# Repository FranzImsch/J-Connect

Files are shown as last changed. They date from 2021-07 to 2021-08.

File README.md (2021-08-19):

# J-Link Adapter Boards

20P JTAG to TAG-Connect TC2030 and  
20P JTAG to 10P JTAG (1.27mm) adapter boards.

### Features:
* 5V to 3.3V LDO and power good LED,
* button to reset the target device,
* VCOM breakout.

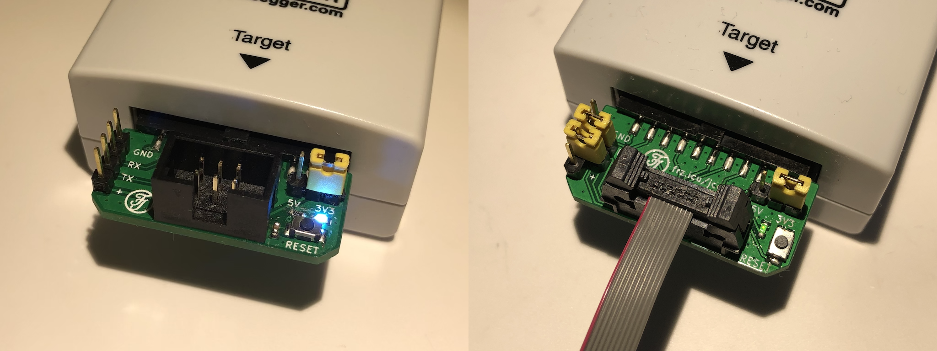
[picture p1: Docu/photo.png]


### PCB
The ideal PCB thickness would be 2.0mm, but 1.6mm is much cheaper and works as well.

## Tag-Connect Adapter
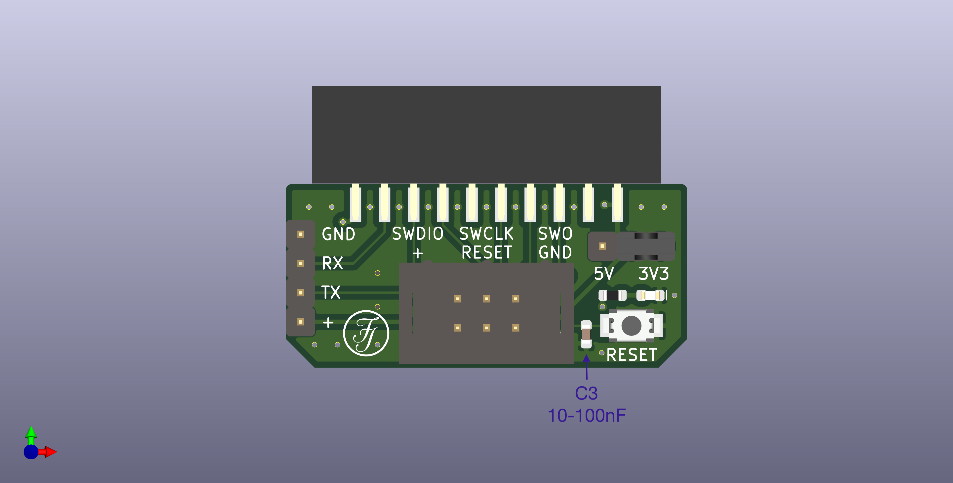
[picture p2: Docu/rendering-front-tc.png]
Front-Rendering

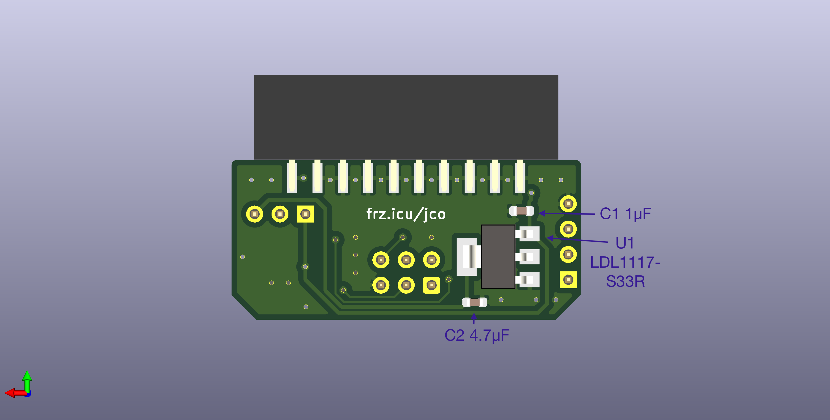
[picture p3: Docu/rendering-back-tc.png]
Back-Rendering


## 10P Adapter
A jumper can be added to connect RX and TX to the pins 7 and 8 respectively. (TX and RX are not in the standard 10P pinout!)  

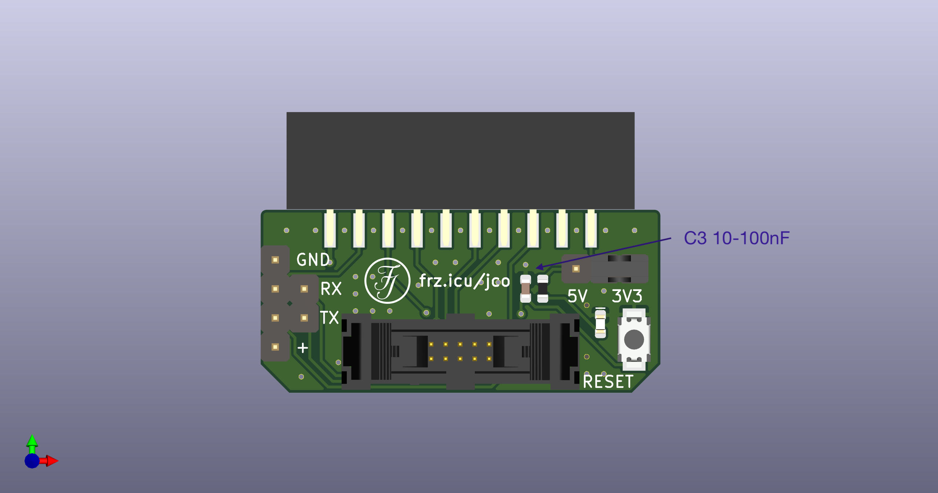
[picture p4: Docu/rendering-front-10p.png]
Front-Rendering

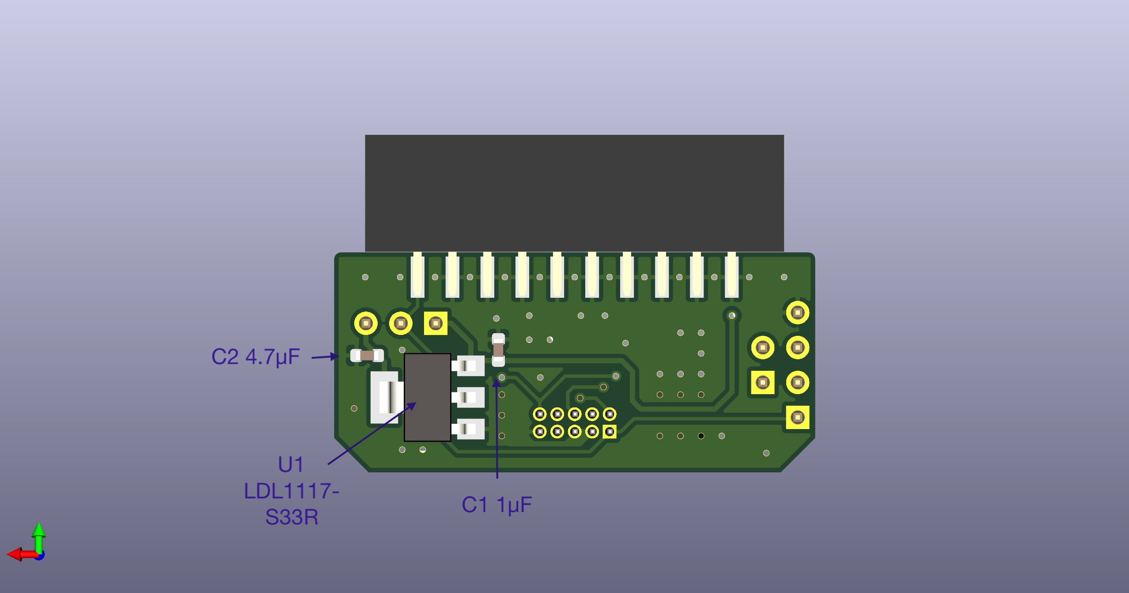
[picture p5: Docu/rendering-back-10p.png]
Back-Rendering


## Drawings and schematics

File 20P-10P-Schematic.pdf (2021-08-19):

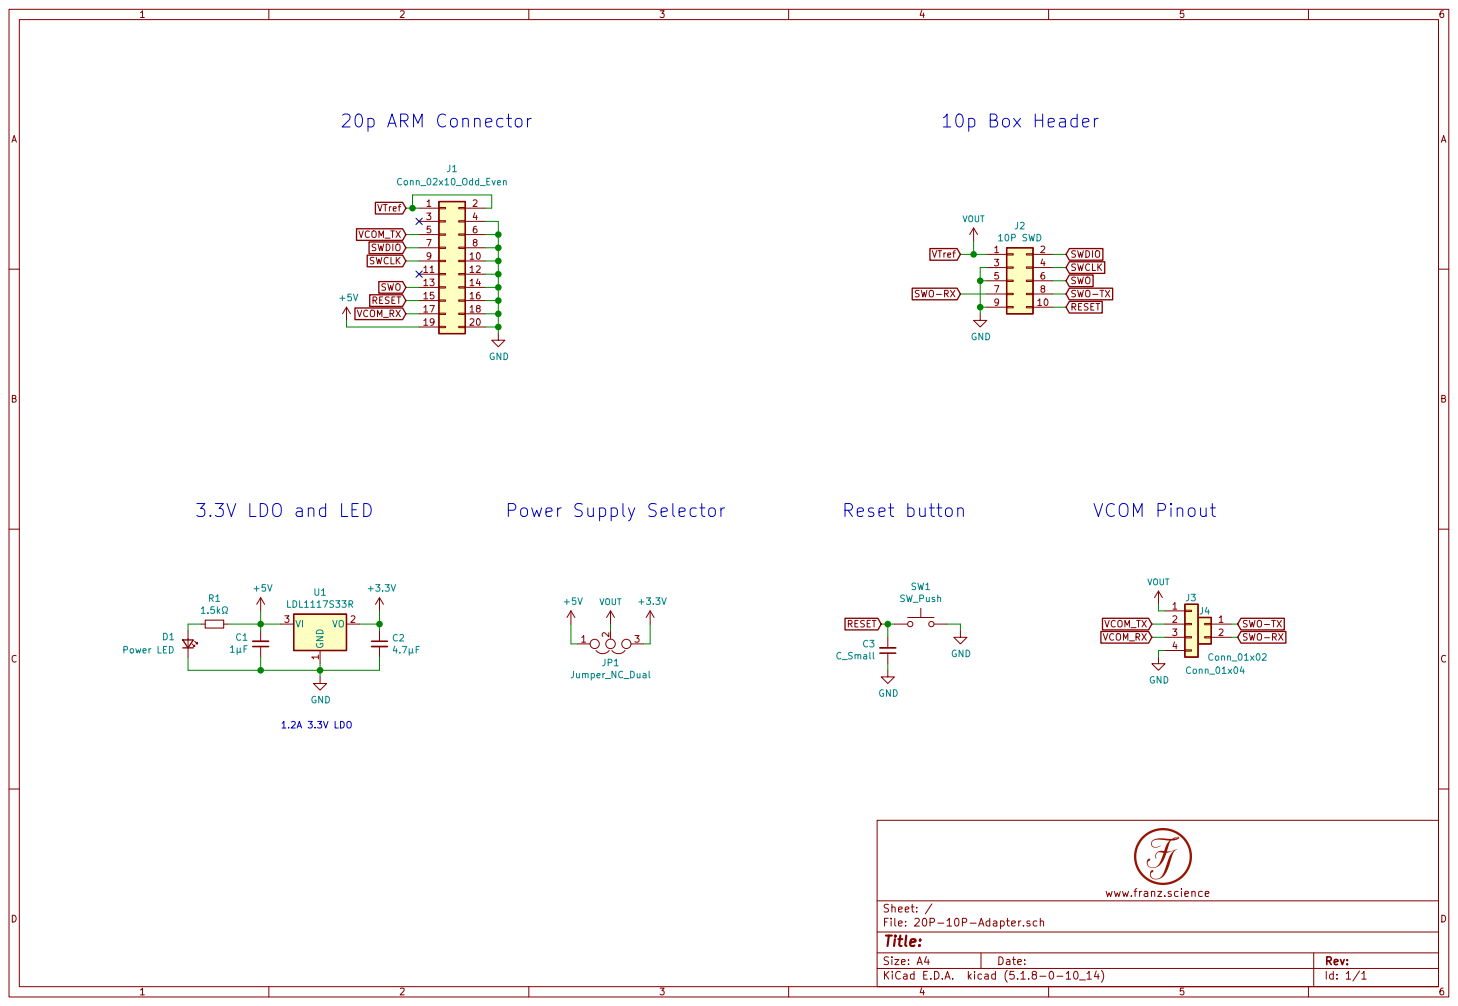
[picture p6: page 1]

File: 20P-10P-Adapter.sch Sheet: /
Id: 1/1 Title:

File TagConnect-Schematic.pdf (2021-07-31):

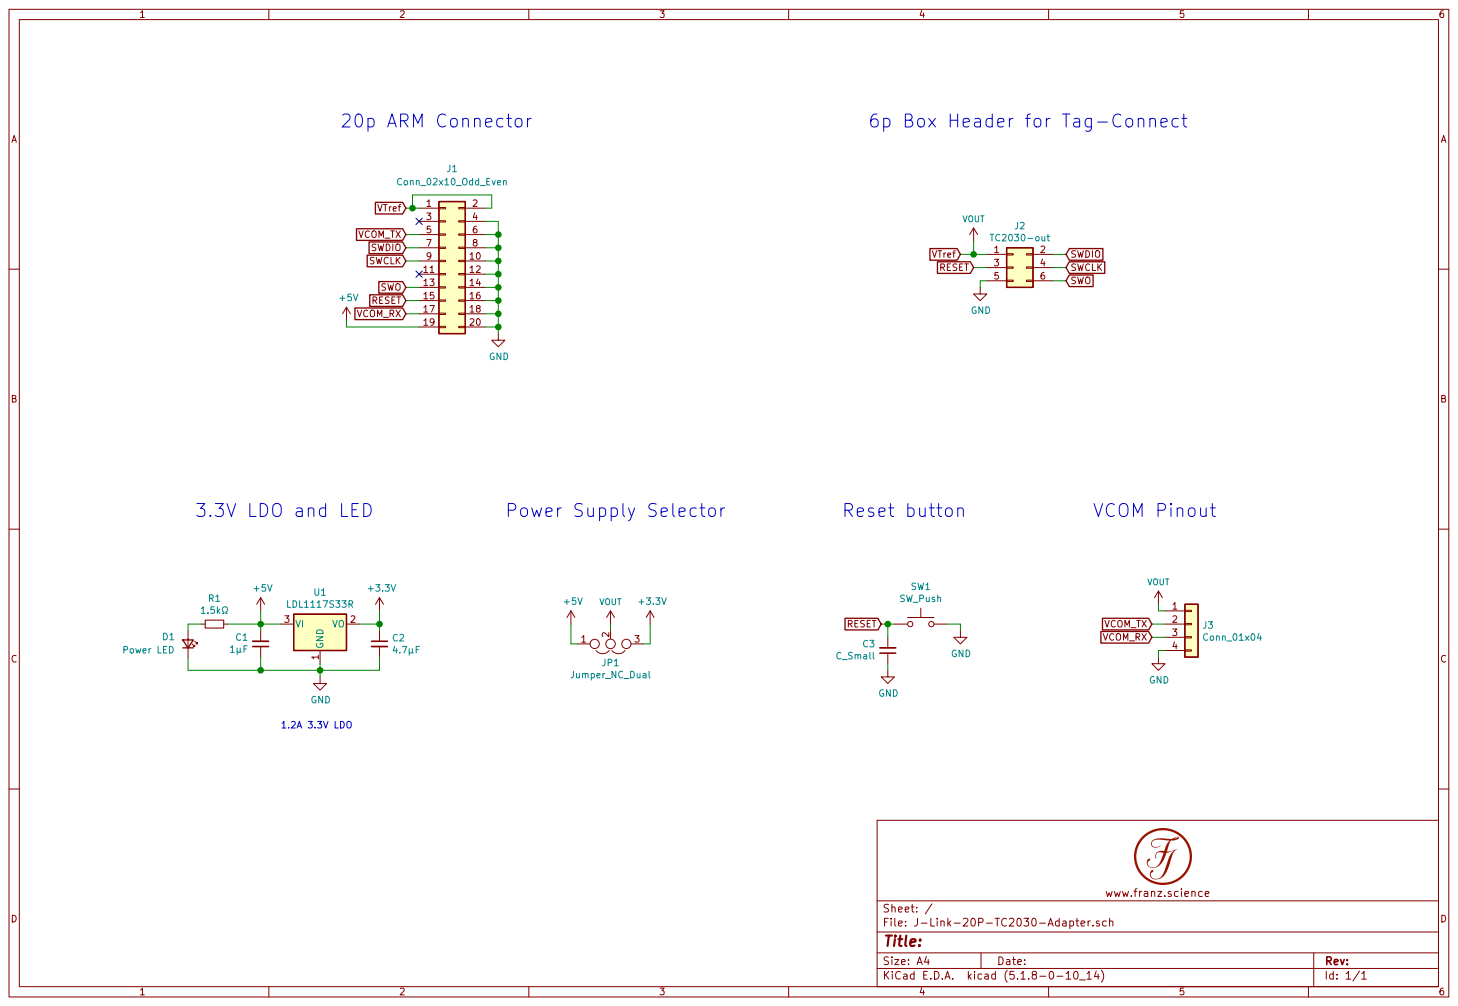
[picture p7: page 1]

File: J-Link-20P-TC2030-Adapter.sch Sheet: /
Id: 1/1 Title:

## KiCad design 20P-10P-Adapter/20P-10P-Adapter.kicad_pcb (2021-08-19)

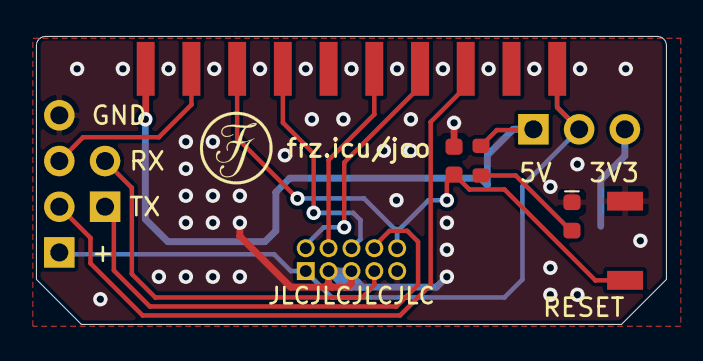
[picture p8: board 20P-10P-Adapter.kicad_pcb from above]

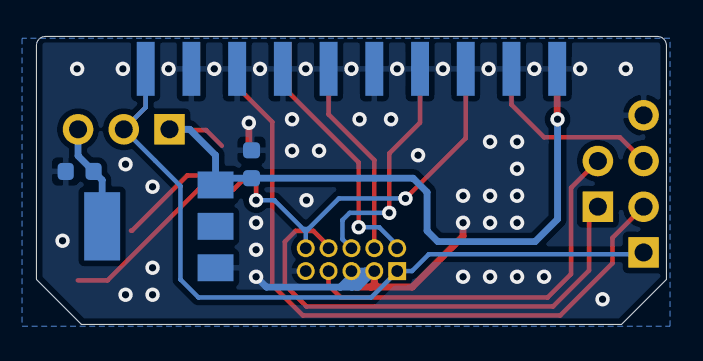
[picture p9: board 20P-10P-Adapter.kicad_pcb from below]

Board: 2 copper layers, 35.0 x 16.0 mm, 12 parts (3 on the bottom side), 13 nets.

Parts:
C1: 1µF; C_0603_1608Metric
C2: 4.7µF; C_0603_1608Metric
C3: C_Small; C_0603_1608Metric
D1: Power LED; LED_0603_1608Metric
J1: Conn_02x10_Odd_Even; Jlink-Conn-20P-PCB
J2: 10P SWD; IDC-Header_2x05_P1.27mm_Latch_Vertical
J3: Conn_01x04; PinHeader_1x04_P2.54mm_Vertical
J4: Conn_01x02; PinHeader_1x02_P2.54mm_Vertical
JP1: Jumper_NC_Dual; PinHeader_1x03_P2.54mm_Vertical
R1: 1.5kΩ; R_0603_1608Metric
SW1: SW_Push; SW_DIP_SPSTx01_Push_TSA343G00-250J2
U1: LDL1117S33R; SOT-223-3_TabPin2

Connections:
+3V3: C2.1, JP1.3, U1.2
+5V: C1.2, J1.19, JP1.1, R1.1, U1.3
GND: C1.1, C2.2, C3.1, D1.1, J1.4, J1.6, J1.8, J1.10, J1.12, J1.14, J1.16, J1.18, J1.20, J2.3, J2.5, J2.9, J3.4, SW1.2, U1.1
unnamed: D1.2, R1.2
RESET: C3.2, J1.15, J2.10, SW1.1
SWCLK: J1.9, J2.4
SWDIO: J1.7, J2.2
SWO: J1.13, J2.6
SWO-RX: J2.7, J4.2
SWO-TX: J2.8, J4.1
VCOM_RX: J1.17, J3.3
VCOM_TX: J1.5, J3.2
VTref: J1.1, J1.2, J2.1, J3.1, JP1.2

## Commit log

2021-07-31 initialising repo
    [J-Link-20P-TC2030-Adapter.kicad_pcb, J-Link-20P-TC2030-Adapter.sch]
2021-08-19 added 10P. adapter board
    [20P-10P-Adapter.kicad_pcb, 20P-10P-Adapter.sch, J-Link-20P-TC2030-Adapter.kicad_pcb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]
